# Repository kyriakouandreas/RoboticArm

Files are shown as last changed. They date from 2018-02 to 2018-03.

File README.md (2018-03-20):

# Robotic Arm

## Introduction 
This project aims to provide a practical tool semiautomated to work in control environments as labs where the contamination of the human hand, for example, is not allowed in certain samples. The movement is control by a user through an interface and physical buttons as well. 
The semiautomated is related to the constant sensing of the temperature for keeping the hand save from sudden temperatures raisings. Besides, the sensing of the pressure is for controlling the strength of the grap perform for the clamp.

It can also be an intelligent crane for a Kid and a nice DIY project. Also, an example of using threads in raspberry pi using c++ and Qt

[ see our wiki! ](https://github.com/kyriakouandreas/RoboticArm/wiki)

[ watch a video of the finished project](https://youtu.be/8hPd8vS8S5o)

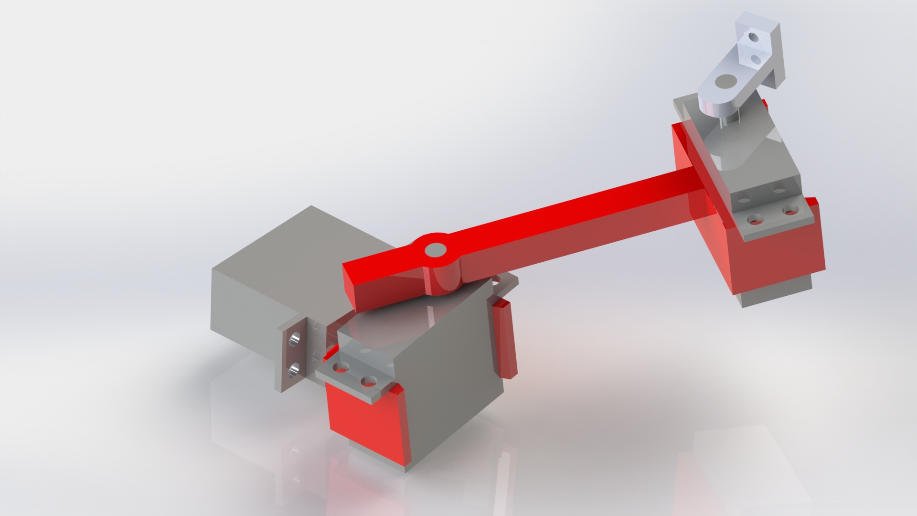
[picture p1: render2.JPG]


## Contributors 
- Sharraf Eltelbani
- Daniel Alvarez Geronimo
- Andreas Kyrikaou

## Parts 
- 4*servos the model             (LewanSoul LD-3015MG)
- 1*metallic claw                (MagiDeal Aluminium Mechanical Robotic Arm Clamp Claw Mount)
- some 3D printed parts          (look in the mech des folder to see them)
- i2c controlled servo driver ic (from [hobby electronics](http://www.hobbytronics.co.uk/servo-controller-12ch-ht))
- 3*push buttons  
- raspberry pi 3
- pcb's                          (look at the pcb folder for more detail)

## Requirments
- Control each motor individually on the interface.
- Allow the possibility of controlling both motors selected by the user with physicals buttons to perform more complex movements
- The values of temperature should show on the screen to keep a record of the trends of it
- Security actions as Resets buttons on both, the interface and the physical panel
- Indicators of the process
- Portable and hand shape
- Protect the sample from being accidentally crushed by the user
- Good responsiveness to commands

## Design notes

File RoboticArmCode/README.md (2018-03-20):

# Qt-RPI_Robotic Arm Shell

The porpouse of this shell is to incorporate on it the advances on each phase. To be able to make a branch of it and 
after performing Unit Test to each part it can then be incorporated to the master branch. 

At the end of the process in here we will have the final code and Software instructions to make it 
work.
The hardware instructions will be in other README file on the master branch and on The WIKI. More information about code structure is on the WIKI. Here are the installation instructions and status on the code.

5/3/2018:
The present program incorporate the reading and display of the readings of the sensors. Also, the controll of the motors using the servo slave i2c and the use of two buttons to control any of the motors select it by the user.

20/3/2018 (v3):
It has fix some GUI updates missing. First try together with the hardware mounting on the PCB, no bread board anymore. It still missing the close loop for the pressure. So, if try this version (Also on YouTube https://www.youtube.com/watch?v=8hPd8vS8S5o) watch for the pressure increase, two hPa above the value when no load is enough for a staedy grap.

# Making it work

Hardware
-----
Go to Hardware instructions for instalation of this project

Software
-----

To clone the git repository:

    git clone https://github.com/kyriakouandreas/RoboticArm.git  

To build:

    cd RoboticArm/RoboticArmCode
    qmake
    make

To run

    ./RoboticArm_Qt-RPI

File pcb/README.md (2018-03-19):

# Robotic Arm PCB
## main idea
the idea is to have all the components in one pcb and have attach to the RPI as a hat.
it was made using proteus software, and all files needed to manufacture it are here as well.
 here is the general schematics of the project
 
## parts and components 
J1: is the servo controler ic. 

J2: is the connection to the RPi.

temp: is the connection to the .

R4, R5: 250 ohms.

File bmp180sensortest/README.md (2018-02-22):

# Qt-RPI_bmp180sensor

An example program using Qt widgets and Raspberry Pi to read from a bmp180 sensor for temperature and pressure. 
It will diplay the temperature on a graph. For accessing the gpio is use the wiringPi library. To comunicate with the sensor is use the I2C serial protocol.

* [Qt5 Homepage](https://www.qt.io/)
* [wiringPiI2C](http://wiringpi.com/reference/i2c-library/)
* [BMP180](http://www.haoyuelectronics.com/Attachment/GY-68/BMP180.pdf)

# Making it work

Hardware
--------------
Power ->   pin 3.3V

SDA   -> GPIO2 (8)

SCL   -> GPIO3 (9)

GND   -> any ground pin

Software
-----

To clone the git repository:

    git clone https://github.com/DevGero/Qt_bmp180_I2C.git  

To build:

    cd Qt_bmp180_I2C
    qmake
    make

To run

    ./bmp180_testProgram

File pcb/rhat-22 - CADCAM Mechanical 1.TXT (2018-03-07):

G04 PROTEUS RS274X GERBER FILE*
%FSLAX24Y24*%
%MOIN*%
%ADD18C,0.0080*%
G54D18*
X-22103Y-9816D02*
X+1039Y-9816D01*
X+1039Y+19114D01*
X-22103Y+19114D01*
X-22103Y-9816D01*
M00*

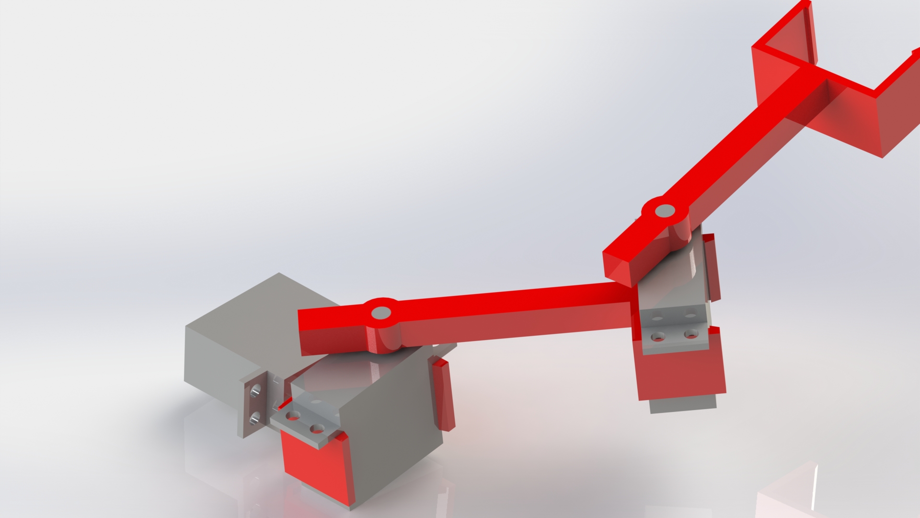
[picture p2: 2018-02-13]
render.JPG

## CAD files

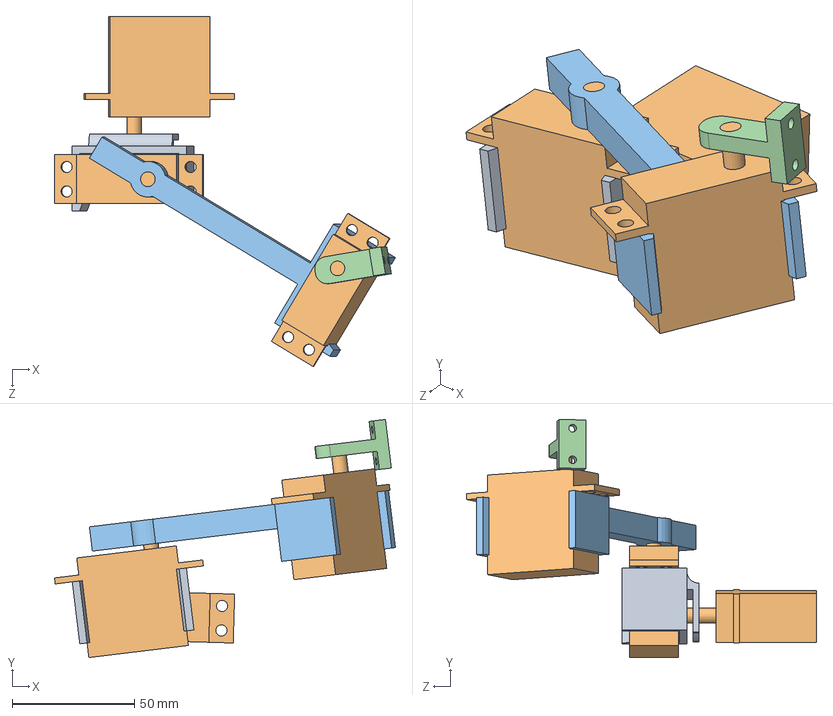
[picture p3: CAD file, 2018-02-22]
mech dis/Assem1.SLDASM
139.3 x 97.3 x 143.0 mm
shoulder 1
servo place holder x 3
shoulder 2
claw holder

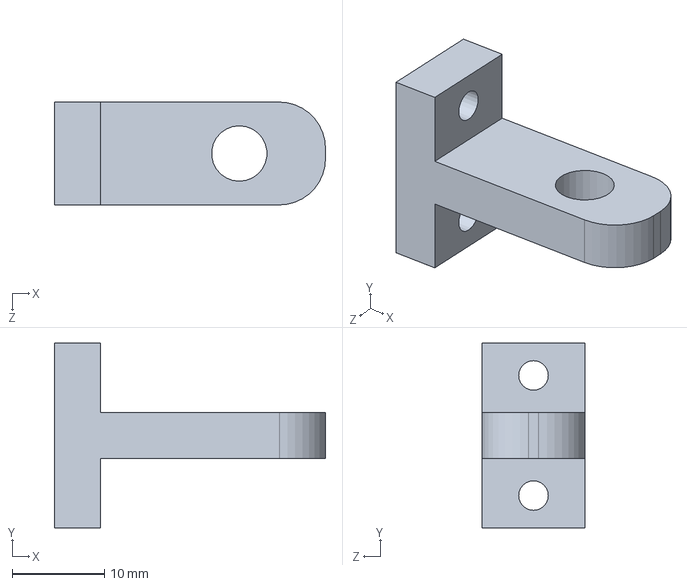
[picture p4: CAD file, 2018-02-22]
mech dis/claw holder.SLDPRT
29.3 x 20.0 x 11.1 mm

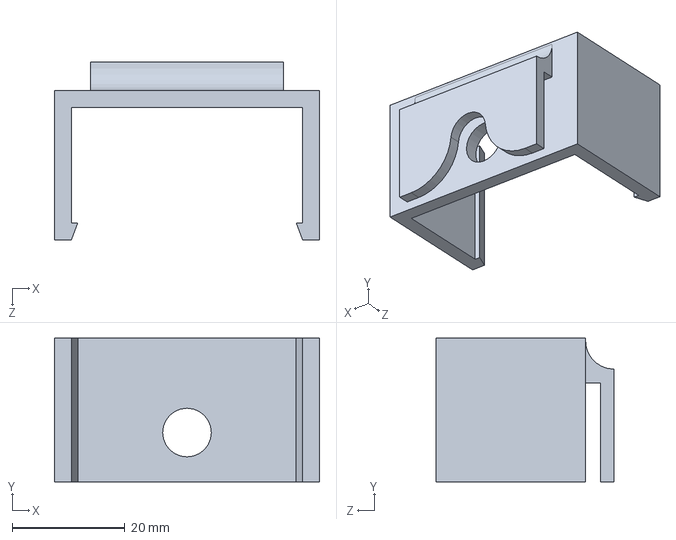
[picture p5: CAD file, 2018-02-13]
mech dis/shoulder 1.SLDPRT
47.0 x 25.5 x 31.5 mm

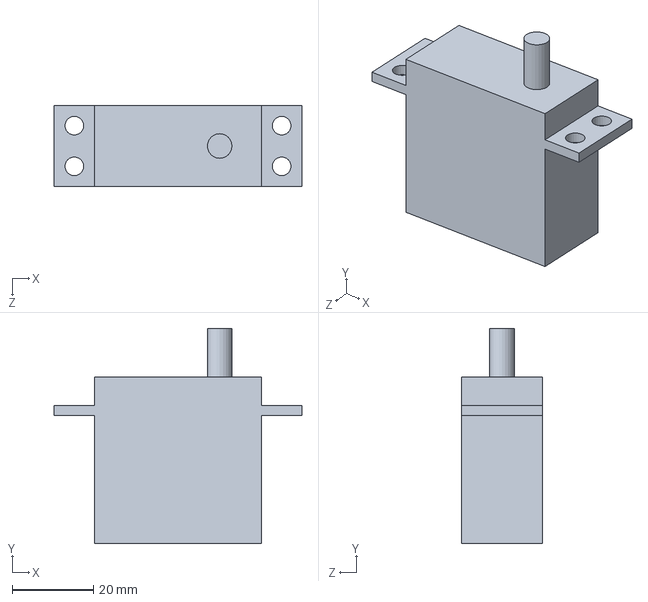
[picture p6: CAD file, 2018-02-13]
mech dis/servo place holder.SLDPRT
61.0 x 53.0 x 20.0 mm

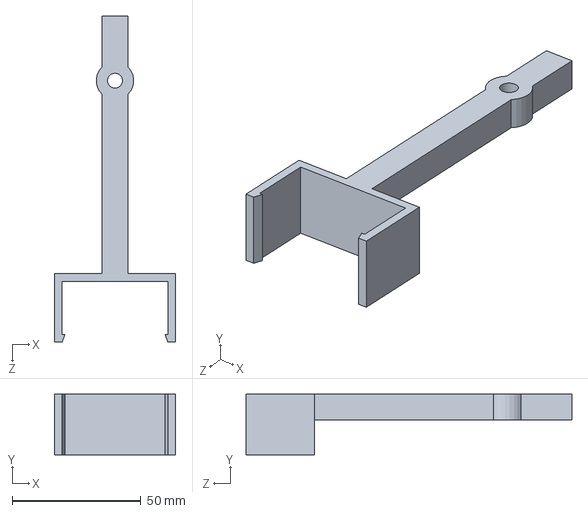
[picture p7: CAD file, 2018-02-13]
mech dis/shoulder 2.SLDPRT
47.0 x 23.5 x 126.5 mm

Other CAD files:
mech dis/claw holder.STL
mech dis/shoulder 1.STL
mech dis/shoulder 2.STL

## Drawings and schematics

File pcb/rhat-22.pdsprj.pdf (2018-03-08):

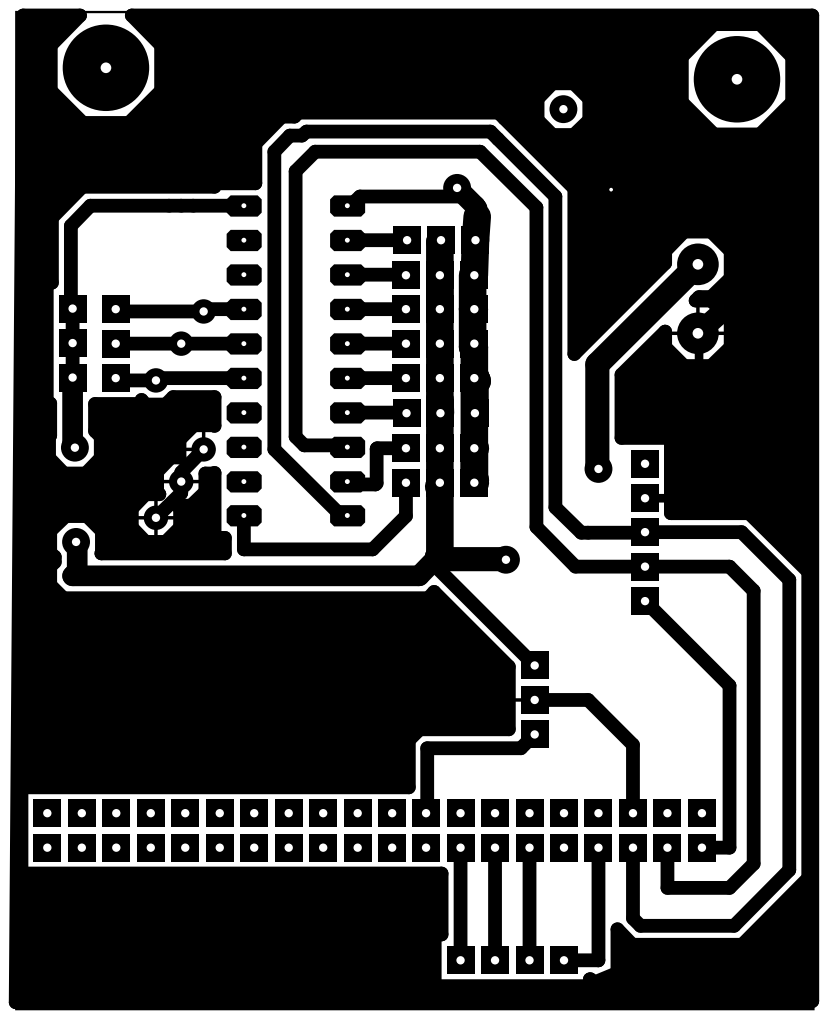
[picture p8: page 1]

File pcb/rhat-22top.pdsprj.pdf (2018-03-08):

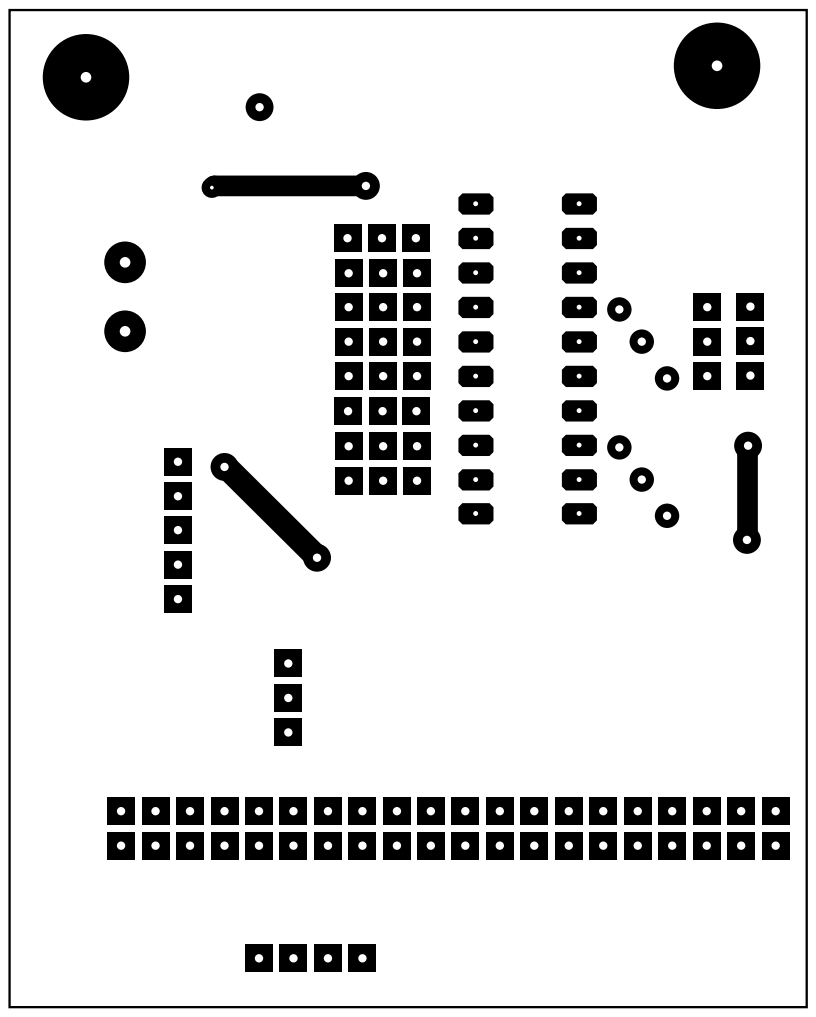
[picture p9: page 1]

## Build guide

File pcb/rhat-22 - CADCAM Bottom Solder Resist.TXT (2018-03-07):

G04 PROTEUS RS274X GERBER FILE*
%FSLAX24Y24*%
%MOIN*%
%ADD22C,0.0400*%
%ADD23C,0.0024*%
%ADD24C,0.0800*%
%ADD25C,0.1300*%
%ADD26C,0.2600*%
%ADD18C,0.0080*%
G54D22*
X-20380Y+6473D03*
X-20328Y+3805D03*
X-5222Y+5891D03*
X-7843Y+3240D03*
X-9289Y+14024D03*
X-4831Y+13963D03*
G54D23*
X-16038Y+13305D02*
X-16038Y+13695D01*
X-15895Y+13838D01*
X-15105Y+13838D01*
X-14962Y+13695D01*
X-14962Y+13305D01*
X-15105Y+13162D01*
X-15895Y+13162D01*
X-16038Y+13305D01*
X-15895Y+13162D02*
X-15105Y+13162D01*
X-15907Y+13174D02*
X-15093Y+13174D01*
X-15919Y+13186D02*
X-15081Y+13186D01*
X-15931Y+13198D02*
X-15069Y+13198D01*
X-15943Y+13210D02*
X-15057Y+13210D01*
X-15955Y+13222D02*
X-15045Y+13222D01*
X-15967Y+13234D02*
X-15033Y+13234D01*
X-15979Y+13246D02*
X-15021Y+13246D01*
X-15991Y+13258D02*
X-15009Y+13258D01*
X-16003Y+13270D02*
X-14997Y+13270D01*
X-16015Y+13282D02*
X-14985Y+13282D01*
X-16027Y+13294D02*
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

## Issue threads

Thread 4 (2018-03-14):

Issues

alex-angelov, 2018-03-14:
1) There is no list of exact component models/manufacturers, or a sketch/CAD of the system design;
2) More information about expected latency between system components, bit rate, needed;
3) Power considerations - will the Pi (assuming you won't use a PSU) be able to supply enough power for the motors;
4) I don't understand what the BMP180 sensor has to do with a robotic arm;
5) RPi CPU benchmarks running parts of the project.
Good idea, but the github page looks a bit convoluted.
-Team 11

sharraftel, 2018-03-15:
Hello,
1- there is a sketch with the stl files too in the "mech dis" folder.
3- if you look at the wiki you will find circuit diagrams, from them you will see that the rpi isnt powering the Motors ( that would be ridiculous)
4 we use that sensor to sense if the temp is too hot for the arm, it is 3d printed after all and we dont want to melt it, and we also use its pressure sensor so that the clamp dont put too much force into the objects it carries.
For the other issues we will put them on the github
:)

sharraftel, 2018-03-19:
hello, all the other issues had been solved, take a look at the wiki
cheers !!

Closed 2018-03-19.

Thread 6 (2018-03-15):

Installation instructions?

tamercos, 2018-03-15:
Not sure if I missed it, but installation instructions would be helpful! :)

Also, the repository is quite convoluted, but then again so is your project. If you can find a way to guide first time viewers effectively that would probably add a lot of value to your repository.

-team 16

DevGero, 2018-03-18:
About the repository,
I am working on the README for the file that contains the latest version of the project code. But basically, the intention is to divide into simpler smaller tasks and avoid long main programs. For example, sensorthread.h and .cpp are in charge of the thread concerning the reading of the sensor but those not know who to access the hardware, this task is encapsulated as a class in bmp180.h and .cpp. That way any change in the GUI, the thread or the low-level access using wiringPi can be easily modified without going through extensive codes and also important can be reused by other person with different requirements. The same works for the i2cservocontroller class that can be accessed from the GUI and the physical buttons.

DevGero, 2018-03-20:
On the WIKI there is a more detail description of the software and his layers. How the tasks are divided and the task of each one and how the objects and threads communicate and interact. This time should be less convoluted.
The installation guide for the software is in the README as well, since we have a version that is working properly. The same that we used for the YouTube video.

sharraftel, 2018-03-20:
the instructions had been added
cheers

Closed 2018-03-20.

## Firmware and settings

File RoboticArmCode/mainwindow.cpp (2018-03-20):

#include "mainwindow.h"
#include "ui_mainwindow.h"

MainWindow::MainWindow(QWidget *parent) :
    QMainWindow(parent),
    ui(new Ui::MainWindow)
{
    ui->setupUi(this);
    //Temp counter init
    high_state = 0;

    //Servos Init
    servoi2c = new ServoController(SERCONT_ADDRESS, MODE_EXTND);
    servoi2c->addMotor(ui->sBox_addrSA->value(), 90, 0, 180);
    servoi2c->addMotor(ui->sBox_addrSB->value(), 90, 0, 180);
    servoi2c->addMotor(ui->sBox_addrE->value(),90, 0, 180);
    servoi2c->addMotor(ui->sBox_addrC->value(),90,CLAMP_LOW_LIMIT,CLAMP_HIGH_LIMIT);

    //Sensor thread Init
    sensorThread = new SensorThread();
    time = QTime::currentTime();
    connect(sensorThread,SIGNAL(sensevalues(float,int)),this,SLOT(on_valuesread(float,int)));
    sensorThread->setParent(this);
    sensorThread->start();

    //Buttons Thread
    btnThread = new ButtonsThread(0,0,servoi2c);
    connect(btnThread,SIGNAL(keyrelease(int)),this,SLOT(on_keyrelease(int)));
    connect(btnThread,SIGNAL(updatePos(int)),this,SLOT(on_updatepos(int)));
    btnThread->setParent(this);

    //Setting the Graph
    ui->temp_graph->addGraph();
    ui->temp_graph->graph(0)->setPen(QPen(Qt::blue)); // line color blue for first graph
    ui->temp_graph->graph(0)->setBrush(QBrush(QColor(0, 0, 255, 20))); // first graph will be filled with translucent blue
    ui->temp_graph->xAxis->setLabel("time(sec)");
    ui->temp_graph->yAxis->setLabel("T(C)");

    //Initial Position Config (if possible let posibility from file)
    initPos[CLAMP] = CLAMP_POS;
    initPos[ELBOW] = ELBOW_POS;
    initPos[SHOULDER_A] = SHOULDER_A_POS;
    initPos[SHOULDER_B] = SHOULDER_B_POS;

    g_initPos[CLAMP] = CLAMP_POS;
    g_initPos[ELBOW] = ELBOW_POS;
    g_initPos[SHOULDER_A] = SHOULDER_A_POS;
    g_initPos[SHOULDER_B] = SHOULDER_B_POS;

    g_motorAddr[CLAMP] = ui->sBox_addrC->value();
    g_motorAddr[ELBOW] = ui->sBox_addrE->value();
    g_motorAddr[SHOULDER_A] = ui->sBox_addrSA->value();
    g_motorAddr[SHOULDER_B] = ui->sBox_addrSB->value();

    //Gpio inits
    if (wiringPiSetup() == -1){
           QMessageBox::information(this,"Error conf gpio","The gpio could not be configured");
           QApplication::quit();
    }
    pinMode(LED_RED, OUTPUT);
    digitalWrite(LED_RED, 0);

    wiringPiISR(RESET_BUTTON, INT_EDGE_RISING, &resetPositionISR);
}

MainWindow::~MainWindow()
{
    delete ui;    
    delete servoi2c;
    delete sensorThread;
    delete btnThread;
}

void MainWindow::on_pBtn_reset_clicked()
{
    //Reset Actions
    time = QTime::currentTime();
    resetActions();
    setDials(false);
}

void MainWindow::on_pBtn_close_clicked()
{
    QApplication::quit();
}

void MainWindow::on_pBtn_setinitPos_clicked()
{

}

void MainWindow::on_dial_MotorClamp_valueChanged(int value)
{
    if(ui->sBox_addrC->isEnabled()){
    main_mutex.lock();
    servoi2c->motorPos(ui->sBox_addrC->value(),value);
    main_mutex.unlock();
    }
}

void MainWindow::on_dial_MotorElbow_valueChanged(int value)
{
    if(ui->sBox_addrE->isEnabled()){
    main_mutex.lock();
    servoi2c->motorPos(ui->sBox_addrE->value(),value);
    main_mutex.unlock();
    }
}

void MainWindow::on_dial_MotorSB_valueChanged(int value)
{
    if(ui->sBox_addrSB->isEnabled()){
    main_mutex.lock();
    servoi2c->motorPos(ui->sBox_addrSB->value(),value);
    main_mutex.unlock();
    }
}

void MainWindow::on_dial_MotorSA_valueChanged(int value)
{
    if(ui->sBox_addrSA->isEnabled()){
    main_mutex.lock();
    servoi2c->motorPos(ui->sBox_addrSA->value(),value);
    main_mutex.unlock();
    }
}

void MainWindow::on_keyrelease(){
    btnThread->wait();
    btnThread->terminate();
}

void MainWindow::on_updatepos(int p){
    if(!(ui->sBox_addrSA->isEnabled())){
        ui->dial_MotorSA->setValue(p);
    }
    if(!(ui->sBox_addrSB->isEnabled())){
        ui->dial_MotorSB->setValue(p);
    }
    if(!(ui->sBox_addrE->isEnabled())){
        ui->dial_MotorElbow->setValue(p);
    }
    if(!(ui->sBox_addrC->isEnabled())){
        ui->dial_MotorClamp->setValue(p);
    }
}

void MainWindow::on_valuesread(float _t, int _p){
    double key = time.elapsed()/1000.0; // time elapsed since start of demo, in seconds

    //Temperature Control
    if(_t > ui->dsBox_tempLimit->value()){
        high_state++;
        if(high_state == ALARM_TEMP_COUNT){
            ui->temp_graph->graph(0)->setPen(QPen(Qt::red)); // line color blue for first graph
            ui->temp_graph->graph(0)->setBrush(QBrush(QColor(255, 0, 0, 20)));
            //resetPositionISR();
            resetActions();
            setDials(false);
            digitalWrite(LED_RED, 1);
        }
    }
    else{
        ui->temp_graph->graph(0)->setPen(QPen(Qt::blue)); // line color blue for first graph
        ui->temp_graph->graph(0)->setBrush(QBrush(QColor(0, 0, 255, 20)));

        high_state = 0; //reset real alarm counting

        if(!(ui->dial_MotorSA->isEnabled() && ui->dial_MotorSB->isEnabled())){
            setDials(true);
            digitalWrite(LED_RED, 0);
        }
    }

    ui->temp_graph->graph(0)->addData(key, _t);
    ui->temp_graph->graph(0)->removeDataBefore(key - 15);

    ui->temp_graph->rescaleAxes();
    ui->temp_graph->xAxis->setRange(key, 15, Qt::AlignRight);
    ui->temp_graph->yAxis->setRangeLower(0);

    ui->temp_graph->replot();

    ui->lbl_actualPressure->setText("Pressure : "+QString::number(_p/100)+" hPa");
    ui->lbl_actualTemp->setText("Temperature : "+QString::number(_t)+" C");

}


void MainWindow::on_rBtn_MtrSA_clicked()
{
    if(ui->rBtn_MtrSA->isChecked()){
        btnThread->setBtnFlag(TRUE);
        btnThread->setPosAddress(ui->dial_MotorSA->value(),ui->sBox_addrSA->value());

        ui->sBox_addrSA->setEnabled(FALSE);
        ui->sBox_addrSB->setEnabled(TRUE);
        ui->sBox_addrE->setEnabled(TRUE);
        ui->sBox_addrC->setEnabled(TRUE);

        if(!btnThread->isRunning())
            btnThread->start();
    }
}

void MainWindow::on_rBtn_MtrSB_clicked()
{
    if(ui->rBtn_MtrSB->isChecked()){
        btnThread->setBtnFlag(TRUE);
        btnThread->setPosAddress(ui->dial_MotorSB->value(),ui->sBox_addrSB->value());

        ui->sBox_addrSA->setEnabled(TRUE);
        ui->sBox_addrSB->setEnabled(FALSE);
        ui->sBox_addrE->setEnabled(TRUE);
        ui->sBox_addrC->setEnabled(TRUE);

        if(!btnThread->isRunning())
            btnThread->start();
    }
}

void MainWindow::on_rBtn_MtrElbow_clicked()
{
    if(ui->rBtn_MtrElbow->isChecked()){
        btnThread->setBtnFlag(TRUE);
        btnThread->setPosAddress(ui->dial_MotorElbow->value(),ui->sBox_addrE->value());

        ui->sBox_addrSA->setEnabled(TRUE);
        ui->sBox_addrSB->setEnabled(TRUE);
        ui->sBox_addrE->setEnabled(FALSE);
        ui->sBox_addrC->setEnabled(TRUE);

        if(!btnThread->isRunning())
            btnThread->start();
    }
}

void MainWindow::on_rBtn_MtrClaw_clicked()
{
    if(ui->rBtn_MtrClaw->isChecked()){
        btnThread->setBtnFlag(TRUE);
        btnThread->setPosAddress(ui->dial_MotorClamp->value(),ui->sBox_addrC->value());

        ui->sBox_addrSA->setEnabled(TRUE);
        ui->sBox_addrSB->setEnabled(TRUE);
        ui->sBox_addrE->setEnabled(TRUE);
        ui->sBox_addrC->setEnabled(FALSE);

        if(!btnThread->isRunning())
            btnThread->start();
    }
}

void MainWindow::on_rBtn_MtrNone_clicked()
{
    if(ui->rBtn_MtrNone->isChecked()){
        btnThread->setBtnFlag(FALSE);

        ui->sBox_addrSA->setEnabled(TRUE);
        ui->sBox_addrSB->setEnabled(TRUE);
        ui->sBox_addrE->setEnabled(TRUE);
        ui->sBox_addrC->setEnabled(TRUE);
    }
}

void MainWindow::on_vSdr_speed_sliderMoved(int position)
{
    btnThread->setmspeed(position);
}

void MainWindow::resetActions(){

    ui->dial_MotorClamp->setValue(initPos[CLAMP]);
    delay(5);//To not throw the sample
    ui->dial_MotorElbow->setValue(initPos[ELBOW]);
    ui->dial_MotorSB->setValue(initPos[SHOULDER_B]);
    ui->dial_MotorSA->setValue(initPos[SHOULDER_A]);

    //Asking is Thread active to ended too
    if(!ui->rBtn_MtrNone->isChecked()){
        btnThread->setBtnFlag(false);
        ui->rBtn_MtrNone->setChecked(true);
    }
}

void MainWindow::setDials(bool state){
    ui->dial_MotorClamp->setEnabled(state);
    ui->dial_MotorElbow->setEnabled(state);
    ui->dial_MotorSB->setEnabled(state);
    ui->dial_MotorSA->setEnabled(state);
}

void resetPositionISR(){
    ServoController resetServo(SERCONT_ADDRESS,MODE_EXTND);
    resetServo.addMotor(g_motorAddr[CLAMP], g_initPos[CLAMP], CLAMP_LOW_LIMIT, CLAMP_HIGH_LIMIT);
    resetServo.addMotor(g_motorAddr[ELBOW], g_initPos[ELBOW], 0, 180);
    resetServo.addMotor(g_motorAddr[SHOULDER_B], g_initPos[SHOULDER_B], 0, 180);
    resetServo.addMotor(g_motorAddr[SHOULDER_B], g_initPos[SHOULDER_A], 0, 180);


    //QApplication::quit();
}

void MainWindow::on_sBox_addrSA_valueChanged(int arg1)
{
    g_motorAddr[SHOULDER_A] = arg1;
}

void MainWindow::on_sBox_addrSB_valueChanged(int arg1)
{
    g_motorAddr[SHOULDER_B] = arg1;
}

void MainWindow::on_sBox_addrE_valueChanged(int arg1)
{
    g_motorAddr[ELBOW] = arg1;
}

void MainWindow::on_sBox_addrC_valueChanged(int arg1)
{
    g_motorAddr[CLAMP] = arg1;
}

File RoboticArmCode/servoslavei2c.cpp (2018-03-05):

#include "servoslavei2c.h"

int fd;

void I2C_writeByte(int reg, int val){
    wiringPiI2CWriteReg8(fd,reg,val);
}

void setup_servocontrol(char m){
    I2C_writeByte(MODE_REG,m);
    delay(1);
}

ServoMotor::ServoMotor(int adr,  int _p, int _la, int _an){
    addr = adr;

    angle_limit = _an;
    l_angle_limit = _la;

    if(_p < l_angle_limit || _p > angle_limit)
        _p = (int)(l_angle_limit + angle_limit)/2;

    int pos = (int)_p*HIGH_LIMIT/_an;
    if(pos < LOW_LIMIT || pos > HIGH_LIMIT)
        pos = (int)(LOW_LIMIT+HIGH_LIMIT)/2;
    I2C_writeByte(adr, pos);
    delay(1);

    position = pos;
}

void ServoMotor::setAddr(int adr){
    addr = adr;
}

void ServoMotor::setPosition(int _p){
    int pos = (int)_p*HIGH_LIMIT/180;

    if(pos < LOW_LIMIT || pos > HIGH_LIMIT)
        pos = (int)(LOW_LIMIT+HIGH_LIMIT)/2;

    I2C_writeByte(addr, pos);
    delay(1);

    position = pos;
}

//***********************************************

ServoController::ServoController(int _icadr, int _m){

    wiringPiSetup();
    fd = wiringPiI2CSetup(_icadr);

    setup_servocontrol(_m);
    
    motors = new ServoMotor*[AMOUNT_LIMIT];

    for(int i = 0; i < AMOUNT_LIMIT; i++){
        motors[i] = new ServoMotor(i);
    }
}

bool ServoController::motorExist(int adr){
    return (motors[adr] != NULL);
}

void ServoController::addMotor(int adr, int _p,int _la, int _an){
       //re-config existent motor
        motors[adr]->setAddr(adr);        
        motors[adr]->setPosition(_p);
        motors[adr]->setAnglelimit(_la, _an);   
}

bool ServoController::removeMotor(int adr){
    if(motorExist(adr)){
        delete motors[adr];
        return true;
    }
    return false;
}

void ServoController::motorPos(int adr, int _p){
    if(adr < 0 || adr > AMOUNT_LIMIT)
        return;
    motors[adr]->setPosition(_p);
}

void ServoController::allmotorPos(int _p){
    for(int i = 0; i < AMOUNT_LIMIT;i++){
        motors[i]->setPosition(_p);
    }
}

ServoController::~ServoController(){
    for(int i = 0; i < AMOUNT_LIMIT; i++){
        if(motorExist(i))
            delete motors[i];
    }
    delete motors;
}

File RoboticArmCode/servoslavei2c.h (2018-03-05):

#ifndef SERVOSLAVEI2C_H
#define SERVOSLAVEI2C_H

#include <wiringPi.h>
#include <wiringPiI2C.h>
#include <stdio.h>

//Address not FIX. If change externally change in here as well.
#define SERCONT_ADDRESS 0x28

//MODES
#define MODE_STND  0
#define MODE_EXTND 1

//Mode Register
#define MODE_REG 0x14

//Limit Values
#define LOW_LIMIT 0
#define HIGH_LIMIT 255
#define AMOUNT_LIMIT 12

//Servo address
#define SERVO_0  0
#define SERVO_1  1
#define SERVO_2  2
#define SERVO_3  3
#define SERVO_4  4
#define SERVO_5  5
#define SERVO_6  6
#define SERVO_7  7
#define SERVO_8  8
#define SERVO_9  9
#define SERVO_10 0xA
#define SERVO_11 0xB

class ServoMotor{
protected:
    int addr;
    int position;
    int angle_limit;
    int l_angle_limit;
public:
    ServoMotor(int , int i = 90,int l = 0, int h = 180);

    void setAddr(int a);
    void setPosition(int);
    void setAnglelimit(int _lan, int _an){l_angle_limit = _lan, angle_limit = _an;}

    char getPosition(){return position;}
    int getAnglelimit(){return angle_limit;}
    int getLanglelimit(){return l_angle_limit;}
    char getAddr(){return addr;}
};

class ServoController{
protected:
    ServoMotor** motors;
public:
    ServoController(int a = 0x28, int m = 1); //Especified Working Mode
    ~ServoController();

    void addMotor(int , int i = 90, int l = 0, int h = 180);
    bool removeMotor(int);

    bool motorExist(int);

    void motorPos(int, int);
    void allmotorPos(int);

    int getAngleLimit(int adr){return motors[adr]->getAnglelimit();}
    int getLowAngleLimit(int adr){return motors[adr]->getLanglelimit();}
};
#endif // SERVOSLAVEI2C_H

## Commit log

2018-02-13 Add files via upload
    the first one with servos
    [Assem1.SLDASM, servo place holder.SLDPRT, shoulder 1.SLDPRT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]
2018-02-13 Add files via upload
    the render without the claw
2018-02-22 sensor bmp180 test
2018-03-05 Add files via upload
    pcb files v 0.6
2018-03-07 making btns thread less process demanding
2018-03-08 updated the pcb design
2018-03-15 Added a photo to the landing page
